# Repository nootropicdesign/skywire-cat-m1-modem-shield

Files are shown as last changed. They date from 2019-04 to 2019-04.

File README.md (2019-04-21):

# Skywire Shield: Arduino shield for Nimbelink Skywire CAT M1 and NB-IoT modems

This is a design for a simple Arduino shield for Nimbelink Skywire CAT M1 and NB-IoT modems. Nimbelink modems are designed to have compatible pinouts and electrical characteristics, so it is possible to design a carrier board that works for a large variety of modems. The board has a switching power supply that provides 3.8V to the modem. Jumpers can be used to connect the modem's serial RX and TX to the Arduino hardware serial pins or to pins for use with software serial (digital pins 2 and 3).

A standard 6-pin serial header connection is accessible from the bottom of the board. This is because some modem modules come with a very high default serial rate that must be changed before an Arduino can interface with it. For example, the Sequans Monarch modem has a default rate of 921600. Connect with a terminal program on a computer and change this with the command `AT+IPR=19200`.

For a full description of this project, see [this project on the nootropic design Project Lab site](https://nootropicdesign.com/projectlab/2019/04/21/arduino-shield-for-cat-m1-and-nb-iot-modems/).

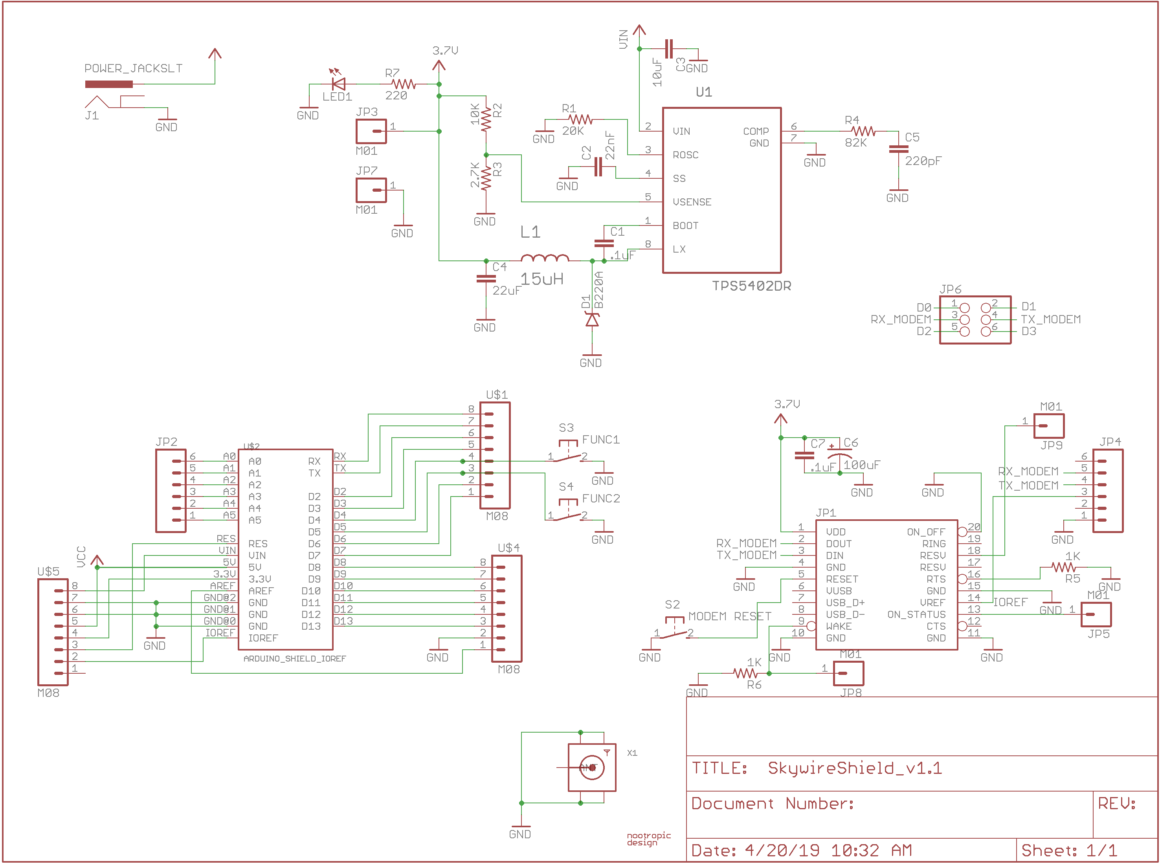
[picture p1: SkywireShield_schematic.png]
Skywire Shield schematic


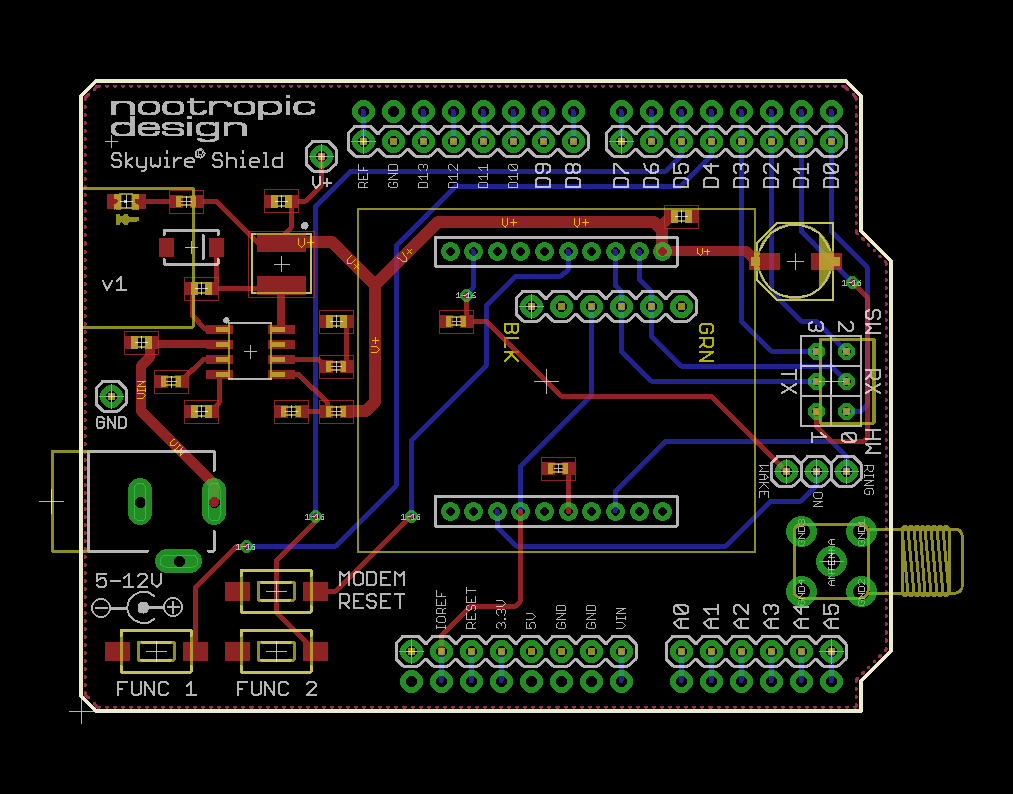
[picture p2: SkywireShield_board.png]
Skywire Shield board


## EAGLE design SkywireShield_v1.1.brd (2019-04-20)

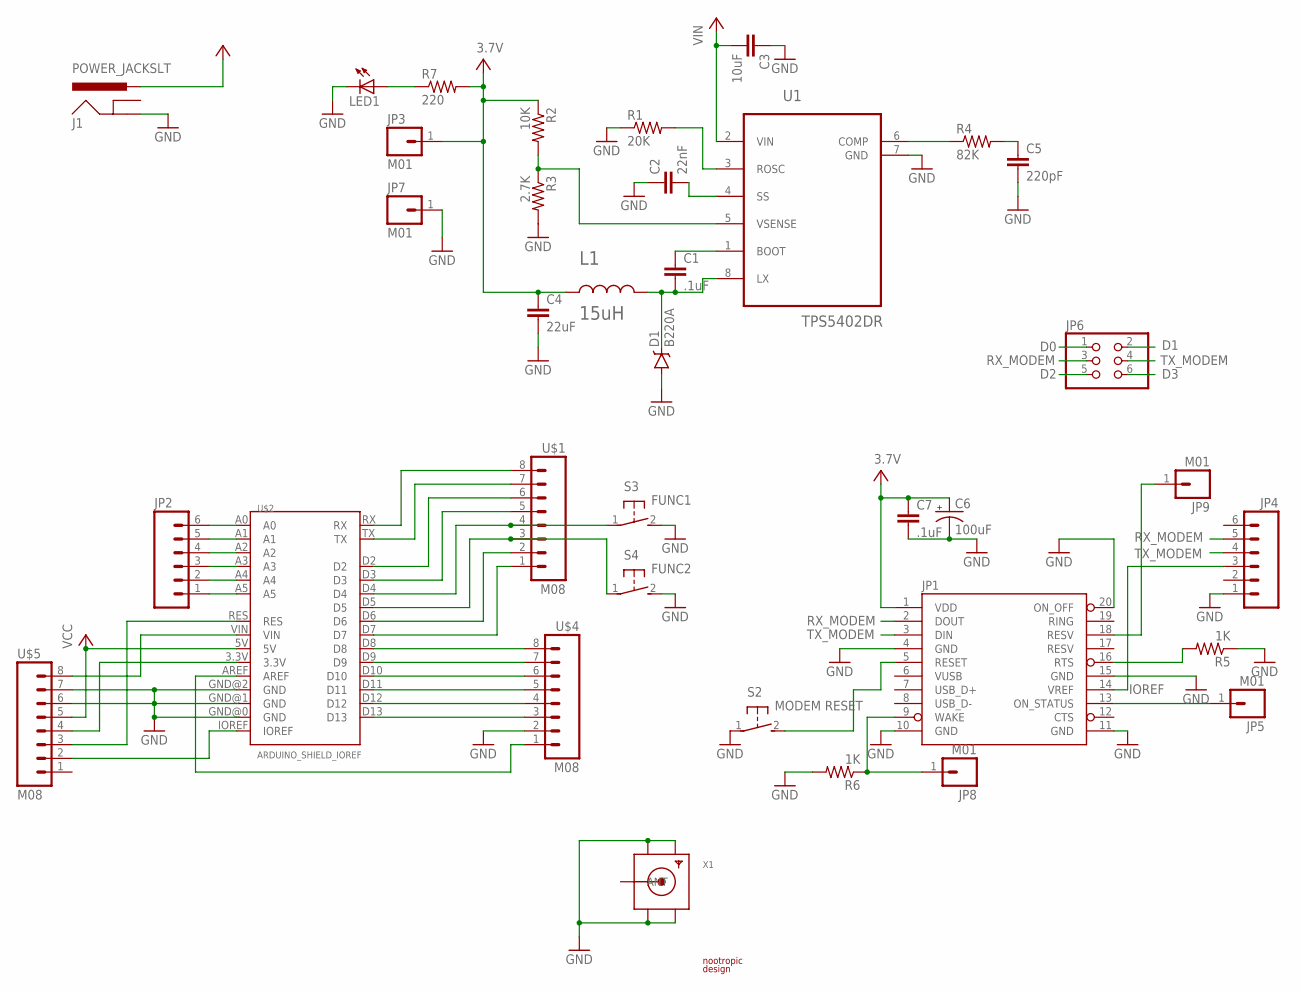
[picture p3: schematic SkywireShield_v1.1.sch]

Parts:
C1, C7: .1uF; C0603
C2: 22nF; C0603
C3: 10uF; C0603
C4: 22uF; C0603
C5: 220pF; C0603
C6: 100uF; PANASONIC_D
D1: B220A; SMA-DIODE
J1: POWER_JACKSLT; POWER_JACK_SLOT
JP1: SKYWIRE_MODEM; SKYWIRE-SOCKET
JP2, JP4: M06; 1X06
JP3, JP5, JP7, JP8, JP9: M01; 1X01
JP6: PINHD-2X3SERIAL-SELECTOR; 2X03-SERIAL-SELECTOR
L1: 15uH; IND_VLS5045EX
LED1: LEDCHIPLED_0805; CHIPLED_0805
R1: 20K; R0603
R2: 10K; R0603
R3: 2.7K; R0603
R4: 82K; R0603
R5, R6: 1K; R0603
R7: 220; R0603
S2: MODEM RESET; DTSM-3
S3: FUNC1; DTSM-3
S4: FUNC2; DTSM-3
U1: TPS5402DR; SOIC8
U$1, U$4, U$5: M08; 1X08
U$2: ARDUINO_SHIELD_IOREF; ARDUINO_SHIELD_GENERIC
U$3: LOGO; LOGO_SMALL
X1: SMACONNECTOR; SMA90_DIP

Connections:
D0: JP6.1, U$1.8, U$2.RX
D1: JP6.2, U$1.7, U$2.TX
D2: JP6.5, U$1.6, U$2.D2
D3: JP6.6, U$1.5, U$2.D3
D4: S3.1, U$1.4, U$2.D4
D5: S4.1, U$1.3, U$2.D5
D6: U$1.2, U$2.D6
D7: U$1.1, U$2.D7
D8: U$2.D8, U$4.8
FB: R2.2, R3.1, U1.5 (VSENSE)
GND: C2.1, C3.1, C4.2, C5.2, C6.-, C7.2, D1.A, J1.GND, JP1.4 (GND), JP1.10 (GND), JP1.11 (GND), JP1.15 (GND), JP1.20 (ON_OFF), JP4.1, JP7.1, LED1.C, R1.1, R3.2, R5.1, R6.2, S2.1, S3.2, S4.2, U1.7 (GND), U$2.GND@0 (GND), U$2.GND@1 (GND), U$2.GND@2 (GND), U$4.2, U$5.6, U$5.7, X1.GND1, X1.GND2, X1.GND3, X1.GND4
IOREF: JP1.14 (VREF), JP4.3, U$2.IOREF, U$5.2
unnamed: JP1.18 (RESV), JP9.1
unnamed: LED1.A, R7.1
unnamed: JP1.16 (RTS), R5.2
unnamed: R1.2, U1.3 (ROSC)
unnamed: C1.1, U1.1 (BOOT)
unnamed: C1.2, D1.C, L1.2, U1.8 (LX)
unnamed: U$2.3.3V, U$5.4
unnamed: JP1.5 (RESET), S2.2
unnamed: U$2.D9, U$4.7
unnamed: U$2.D10, U$4.6
unnamed: U$2.D11, U$4.5
unnamed: U$2.D12, U$4.4
unnamed: U$2.D13, U$4.3
unnamed: C2.2, U1.4 (SS)
unnamed: U$2.AREF, U$4.1
unnamed: JP2.6, U$2.A0
unnamed: JP2.5, U$2.A1
unnamed: JP2.4, U$2.A2
unnamed: JP2.3, U$2.A3
unnamed: JP2.2, U$2.A4
unnamed: JP2.1, U$2.A5
unnamed: U$2.VIN, U$5.8
unnamed: R4.1, U1.6 (COMP)
unnamed: C5.1, R4.2
ON_STATUS: JP1.13 (ON_STATUS), JP5.1
RESET: U$2.RES, U$5.3
RX_MODEM: JP1.2 (DOUT), JP4.5, JP6.3
TX_MODEM: JP1.3 (DIN), JP4.4, JP6.4
V+: C4.1, C6.+, C7.1, JP1.1 (VDD), JP3.1, L1.1, R2.1, R7.2
VCC: U$2.5V, U$5.5
VIN: C3.2, J1.PWR, U1.2 (VIN)
VUSB: JP1.6 (VUSB)
WAKE: JP1.9 (WAKE), JP8.1, R6.1

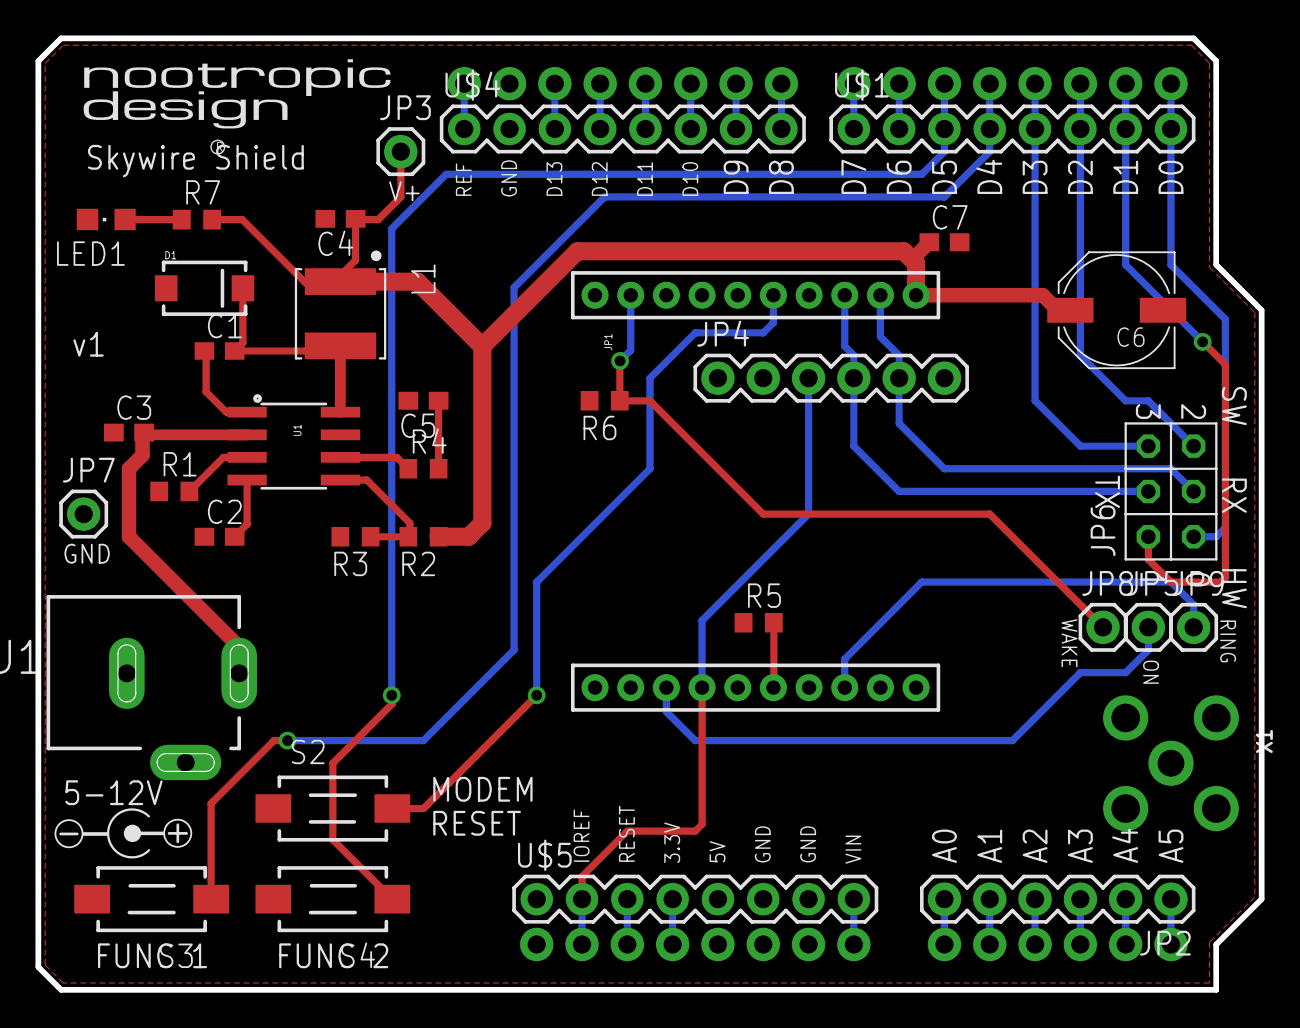
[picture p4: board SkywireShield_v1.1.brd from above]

Board: 2 copper layers, 68.6 x 53.3 mm, 37 parts (0 on the bottom side), 44 nets.

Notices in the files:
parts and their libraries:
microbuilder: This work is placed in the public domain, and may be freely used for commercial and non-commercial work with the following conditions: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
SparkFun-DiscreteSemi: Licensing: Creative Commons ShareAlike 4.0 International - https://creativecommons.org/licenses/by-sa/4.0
